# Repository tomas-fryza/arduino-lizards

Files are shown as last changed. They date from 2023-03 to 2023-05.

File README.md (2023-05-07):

# Measuring track for lizards

* [TODO](#TODO)
* [About](#About)
* [Usage](#Usage)
  * [PuTTY for Windows and Linux](#PuTTY-for-Windows-and-Linux)
  * [Terminal for Windows](#Terminal-for-Windows)
  * [Termite for Windows](#Termite-for-Windows)
* [Programming Arduino using PlatformIO](#Programming-Arduino-using-PlatformIO)
* [References](#References)

## TODO

* [x] Instructions for use & program
* [x] Logging data to a file
* [x] Selecting a suitable Monitor program (PuTTY, Terminal, Terminte, PlatformIO, ...)
* [x] Strengthen the mechanics
* [x] Add "start box"
* [x] Add (semi)waterproof paint
* [x] Cover electronics, 3D printing
* [x] Q: Consumption? A: approx. 350 milliamps
* [x] Q: IR wavelength A: 940 nm
* [ ] Q: Do I need to install USB driver? A: ??

## About

The measuring path contains 11 optical wounds, i.e. pairs of 940 nm infrared diodes and phototransistors. The first gate is the starting gate, the others are spaced 10 centimeters apart. The length of the track is thus 1 meter. Combine temperature and humidity sensor is used as well.

The ATmega328P microcontroller on the Arduino Nano board provides data acquisition from optical gates, time, temperature and humidity measurement, and data sending. The measuring track is powered via a mini USB connector, and at the same time, all data about the measurement progress is sent to the computer/laptop via this USB. Values are separated by semicolumn ";" symbol and can be subsequently processed, for example, in Excel.

## Usage

Once the microcontroller is programmed, on the PC/laptop just run one of the programs that can communicate with the serial port, such as PuTTY, Terminal, Termite, or other.

Perform the following steps to measure the speed of lizards:

1. Connect your computer/laptop to the Arduino board using a USB cable.

2. Run PuTTY, Terminal, Termite, or other serial terminal.

3. Configure terminal to save measured data to log text file.

4. Press `S` on keyboard to start the measurement. Status LED on Arduino board is turn on.

5. Place the lizard in the starting position and let it run through the entire track.

6. The individual times are written to the serial terminal (and the log file) after all gates have been interrupted or after the maximum time has expired. This is set to 60 seconds and can be reprogrammed in the Arduino Nano.

7. Go back to point 4 and repeat.

### PuTTY for Windows and Linux

1. Download, install, and run PuTTY open-source application for [Windows](https://putty.org/) or [Linux](https://www.tecmint.com/install-putty-on-linux/).

2. Set the following parameters:

   a. Category: Session Logging: **Printable output**

   b. Select Log file name, such as: `C:\Documents\your-user-name\putty_&Y&M&D-&T.log`

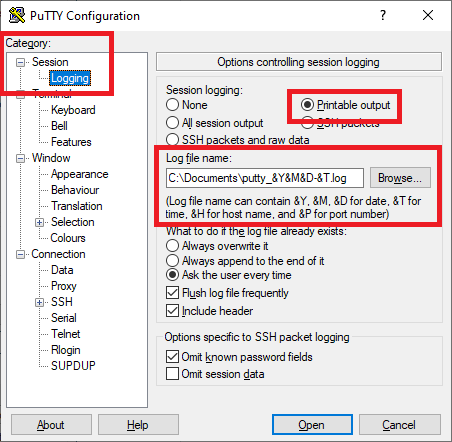
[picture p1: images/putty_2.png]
putty2
      

   c. Change Category to **Session** and select Connection type: **Serial**

   d. Serial line: put your com port, such as **COM5** (Windows) or `/dev/ttyUSB0` (Linux)

      > **Help:** To get the port name, run the Device Manager on Windows or type `dmesg` command to Terminal in Linux.

   e. Speed: **9600**

   f. Name Save Sessions: **LIZARDS** and click on **Save** button

   g. Anytime in the future, there is no need to configure PuTTY again, just double click on saved default settings **LIZARDS** to open the connection.

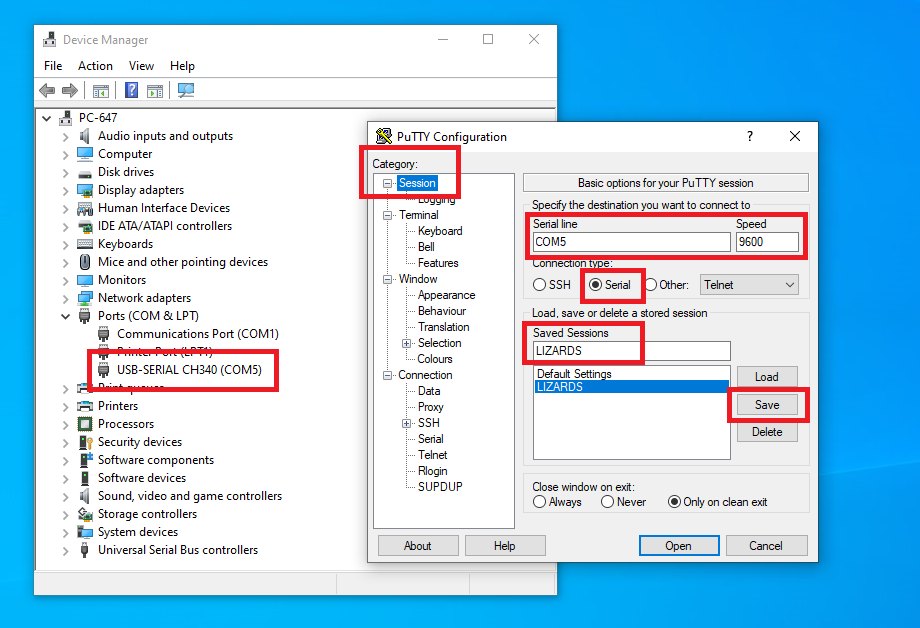
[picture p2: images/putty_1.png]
putty1
      

   h. Press `S` on keyboard to start each measurement.

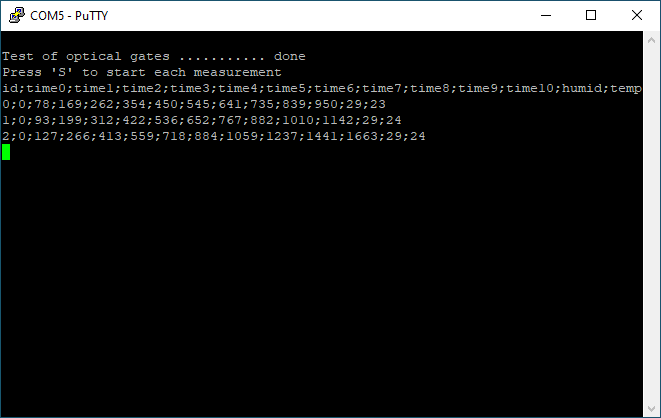
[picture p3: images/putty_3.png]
putty3
      

   i. Values are saved to your log file.

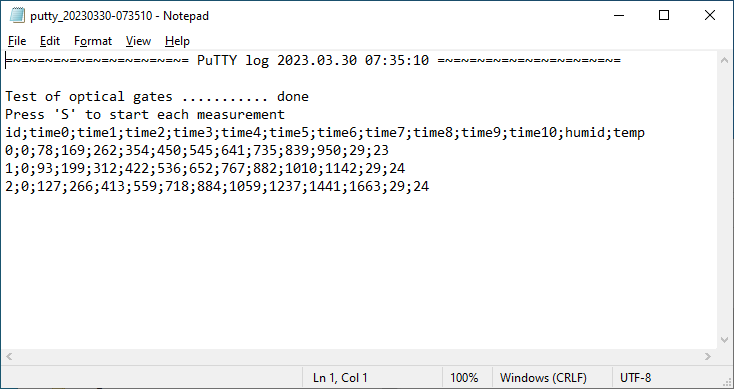
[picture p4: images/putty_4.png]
putty4
      

### Terminal for Windows

1. Download, unzip, and run the [Terminal](https://sites.google.com/site/terminalbpp/) application.

2. TBD

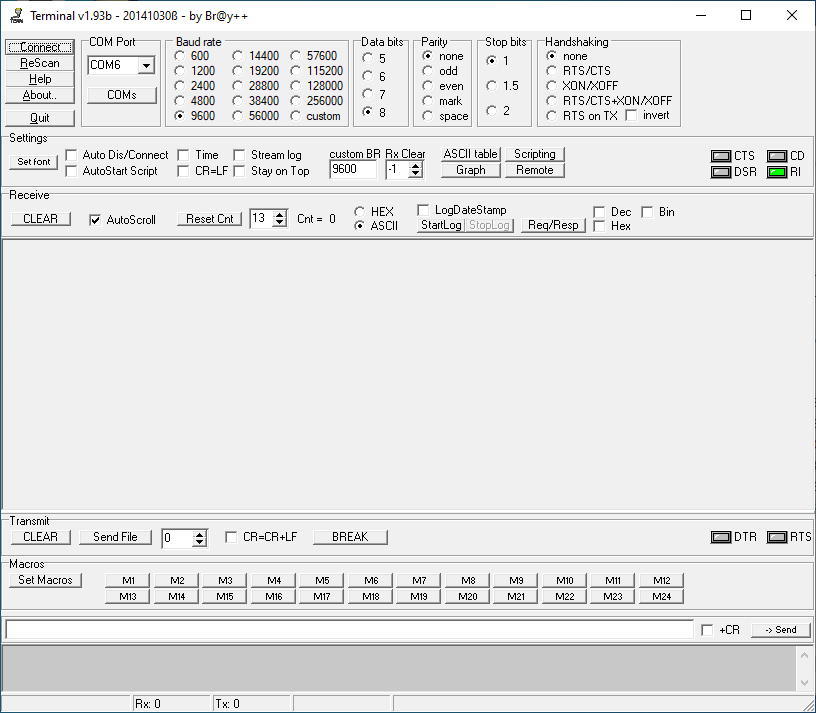
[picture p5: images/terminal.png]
terminal
   

### Termite for Windows

1. Download, install, and run [Termite](https://www.compuphase.com/software_termite.htm#EDITHISTORY) application.

2. TBD

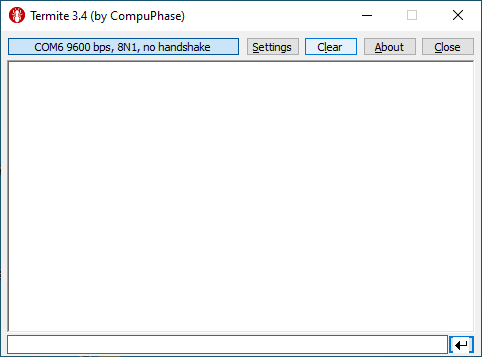
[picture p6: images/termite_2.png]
termite_2
   
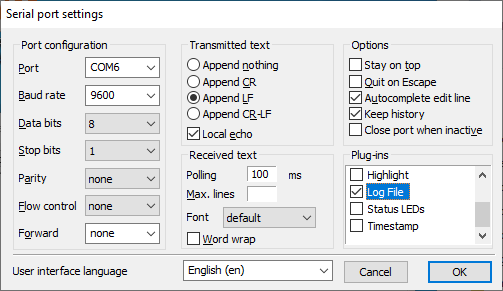
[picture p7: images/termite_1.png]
termite_1
   

## Programming Arduino using PlatformIO

1. Follow [Installation](https://github.com/tomas-fryza/digital-electronics-2/wiki/How-to-use-AVR-template-with-PlatformIO) instruction and download & install Visual Studio Code and PlatformIO plugin.

2. Download this repository, ie. in [browser](https://github.com/tomas-fryza/arduino-lizards), click on green `<> Code` button and select `Download ZIP`. Extract zip file to your local computer.

3. In Visual Studio Code, select **File > Open Folder...** and browse to `arduino-lizards/software/lizards` extracted folder.

4. In `platformio.ini` configuration file change your port name, such as COM5 for Windows:

   ```asm
   ; Custom monitor port
   ; Windows:
   monitor_port = COM[5]
   ; Linux:
   ; monitor_port = /dev/ttyUSB0
   ```

5. The application is programmed in C++ and is located in the file `src > main.cpp`

6. Compile the code, run the application, and open Serial Monitor to control it.

   Control icons

## References

1. Michaela Ryšavá. [Vývoj systému pro měření pohybových schopností malých živočichů](https://www.vut.cz/studenti/zav-prace/detail/141521)

2. Les Pounder. [How To Detect the COM Port for Any Serial Device in Windows](https://www.tomshardware.com/how-to/detect-com-port-windows-serial-port-notifier)

3. Martins D. Okoi. [How to Install PuTTY on Linux](https://www.tecmint.com/install-putty-on-linux/)

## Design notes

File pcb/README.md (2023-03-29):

# List of components

Symbol | Value | Package | Description
 :--   | :--   | :--     | :--
R1 | 10k | SMD 0805 | Resistor
R2 | 50 | SMD 0805 | Resistor
C | 100n | SMD 0603 | Capacitor
LM393D | | S08 | Dual differential comparator
L-53F3BT | | THT | LED IR, 940nm, 5mm
503PTC2E | | THT | Phototransistor, IR Detector 940nm
DG350-3.50-05P-14-02A | | | Screw terminal
BL 1 34 G | | | Female headers

## Possible future revisions

* switching transistors for IR leds
* smd packages for both IR leds and phototransistors
* more accurate temperature measurement
* lower consumption, battery powered
* ESP32, wi-fi/bluetooth comm?
* onboard logging: eeprom, sd card, ...
* display, button
* multiple IR LEDs on top of each other; the possibility of setting the necessary height of the optical gate

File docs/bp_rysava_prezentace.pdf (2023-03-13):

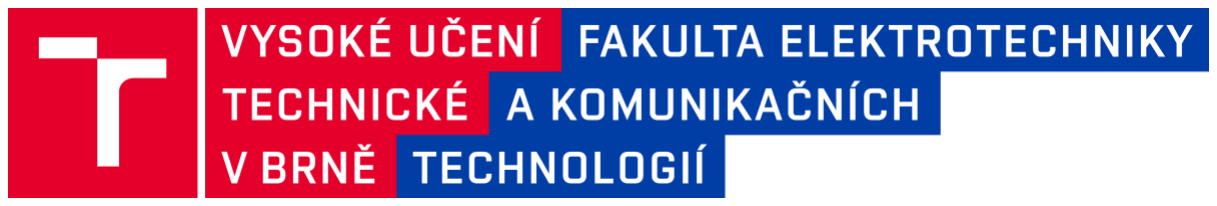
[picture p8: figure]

## Vývoj systému pro měření pohybových schopností malých živočichů

Bakalářská práce

Autor práce: MICHAELA RYŠAVÁ
Vedoucí práce: doc. Ing. TOMÁŠ FRÝZA, Ph.D.
Oponent: | doc. Mgr. KŘESTNÍ PŘÍJMENÍ, Ph.D.
| Brno, 14. 6. 2022

## Cíle práce

Téma
sestavit zařízení pro měření pohybu ještěrek na testovacích drahách Cíle semestrální práce
prozkoumat komerčně dostupné systémy
navrhnout vhodné metody měření a vyhodnocování dat
provést testování spolehlivosti navržených metod
Michaela Ryšavá | Vývoj systému pro měření pohybových schopností malých živočichů | 1 / 12

## Specifikace projektu

Cílem je změřit čas a rychlost na dráze s následujícími parametry:

rozměry:
šířka: 8 cm
délka: 1 m
varianty dráhy:
rovná dráha
zvlněná dráha
dráha ve tvaru U
další parametry:
povrch dráhy: smirkový
papír hrubosti 2000
materiál: plexisklo, dřevo požadavek na
odstranitelný horní kryt

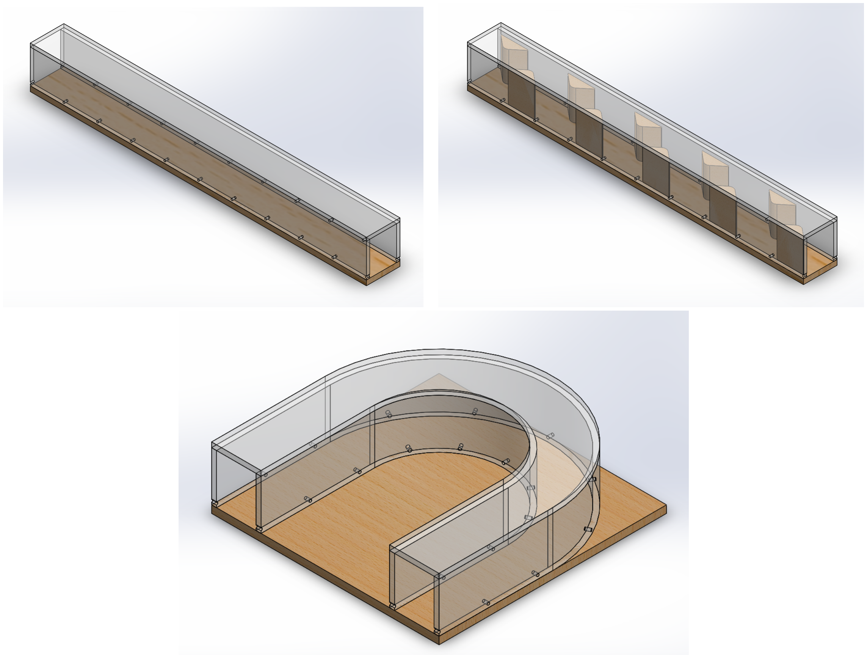
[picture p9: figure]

Michaela Ryšavá | Vývoj systému pro měření pohybových schopností malých živočichů | 2 / 12

## Metody měření

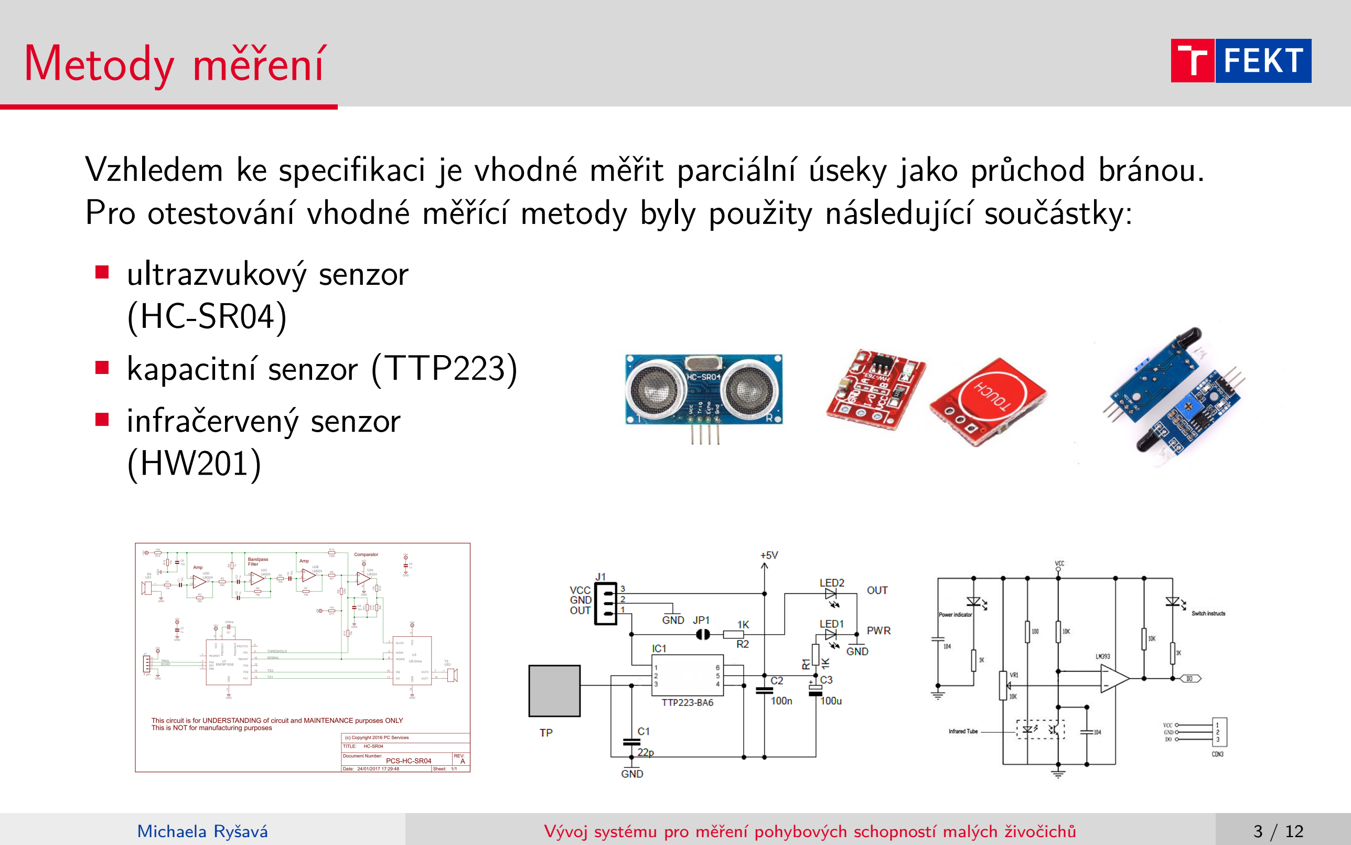
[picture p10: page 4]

Vzhledem ke specifikaci je vhodné měřit parciální úseky jako průchod bránou. Pro otestování vhodné měřící metody byly použity následující součástky:

ultrazvukový senzor
(HC-SR04)
kapacitní senzor (TTP223)
infračervený senzor
(HW201)
Michaela Ryšavá | Vývoj systému pro měření pohybových schopností malých živočichů | 3 / 12

## Výsledky testování metod měření

| Ultrazvukový senzor | Kapacitní senzor | Infračervený senzor | Optická brána
Schopnost detekce ještěrky | Ano | Není možné určit | Ano, na malé vzdálenosti | Ano
Spolehlivost detekce v prostoru 8cm | Ano | Ano | Ne | Ano
Diskrétnost řešení v rámci dráhy | Ano | Ano | Ne | Ano
Snadnost implementace na dráhu | Obtížné z hlediska výroby dráhy | Obtížné z hlediska těsnění | Snadné | Snadné
Nutnost přesné kalibrace | Není potřeba | Je potřeba | Je potřeba | Není potřeba
Citlivost na změny okolí | Zanedbatelné | Vlhkost | Světlo | Světlo
Michaela Ryšavá | Vývoj systému pro měření pohybových schopností malých živočichů | 4 / 12

## Návrh optické brány

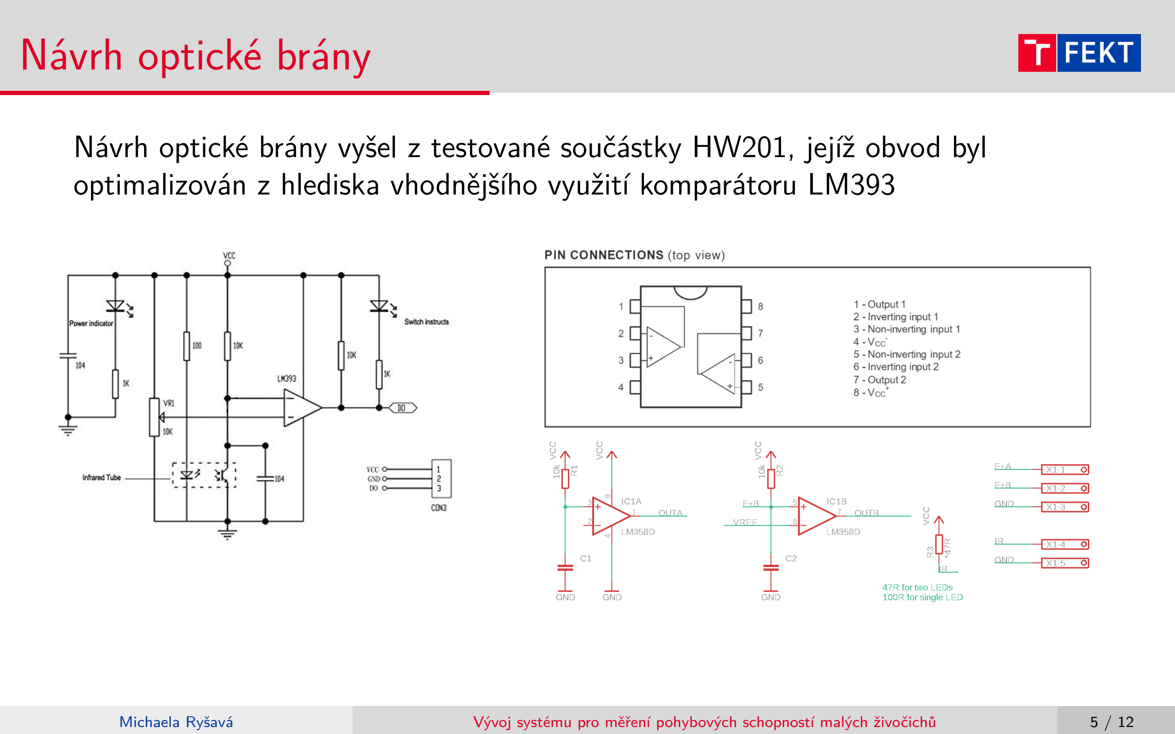
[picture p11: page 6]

Návrh optické brány vyšel z testované součástky HW201, jejíž obvod byl optimalizován z hlediska vhodnějšího využití komparátoru LM393

Michaela Ryšavá | Vývoj systému pro měření pohybových schopností malých živočichů | 5 / 12

## Deska plošných spojů

Rozvržení elektroniky bylo vzhledem k praktickým problémům při konstrukci dráhy soustředěno na jednu desku a podél samotné brány vedou pouze vodiče s optickými prvky.
Použité součástky:
rezistor 10 k, SMD 0805
rezistor 50, SMD 0805
kondenzátor 100 n, SMD 0603 komparátor LM393D, S08
infračervená LED, 5 mm, THT fototranzistor, 5 mm, THT
svorkovnice 5 pól, rozteč 3,5 mm dutinková lišta

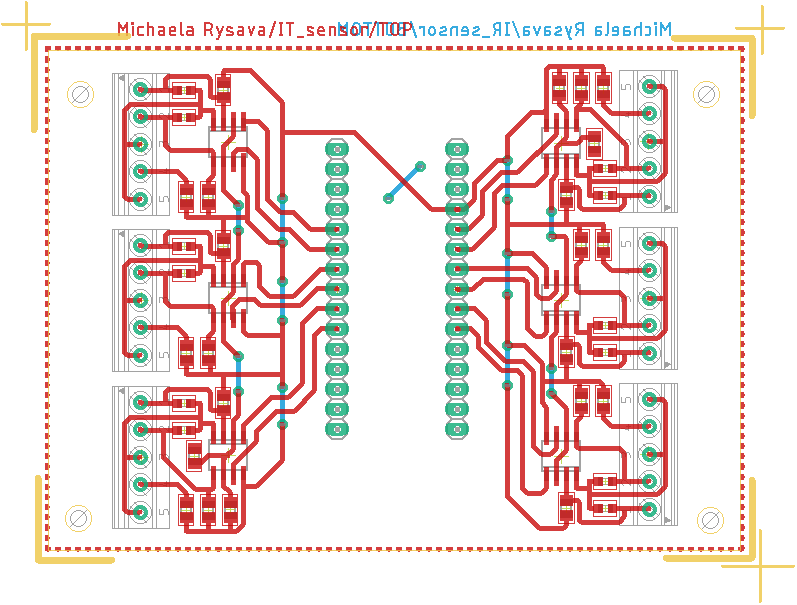
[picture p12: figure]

Michaela Ryšavá | Vývoj systému pro měření pohybových schopností malých živočichů | 6 / 12

## Celkové zapojení

Měřící systém je sestaven z částí:
optické prvky podél dráhy
deska plošných spojů s komparátory řídící jednotka Arduino Nano s firmwarem PC se softwarem

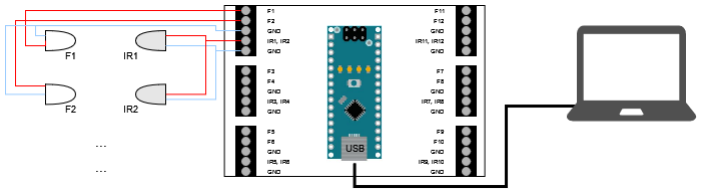
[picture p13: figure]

Michaela Ryšavá | Vývoj systému pro měření pohybových schopností malých živočichů | 7 / 12

## Programová část

Měření je ovládáno ze softwaru na počítači.

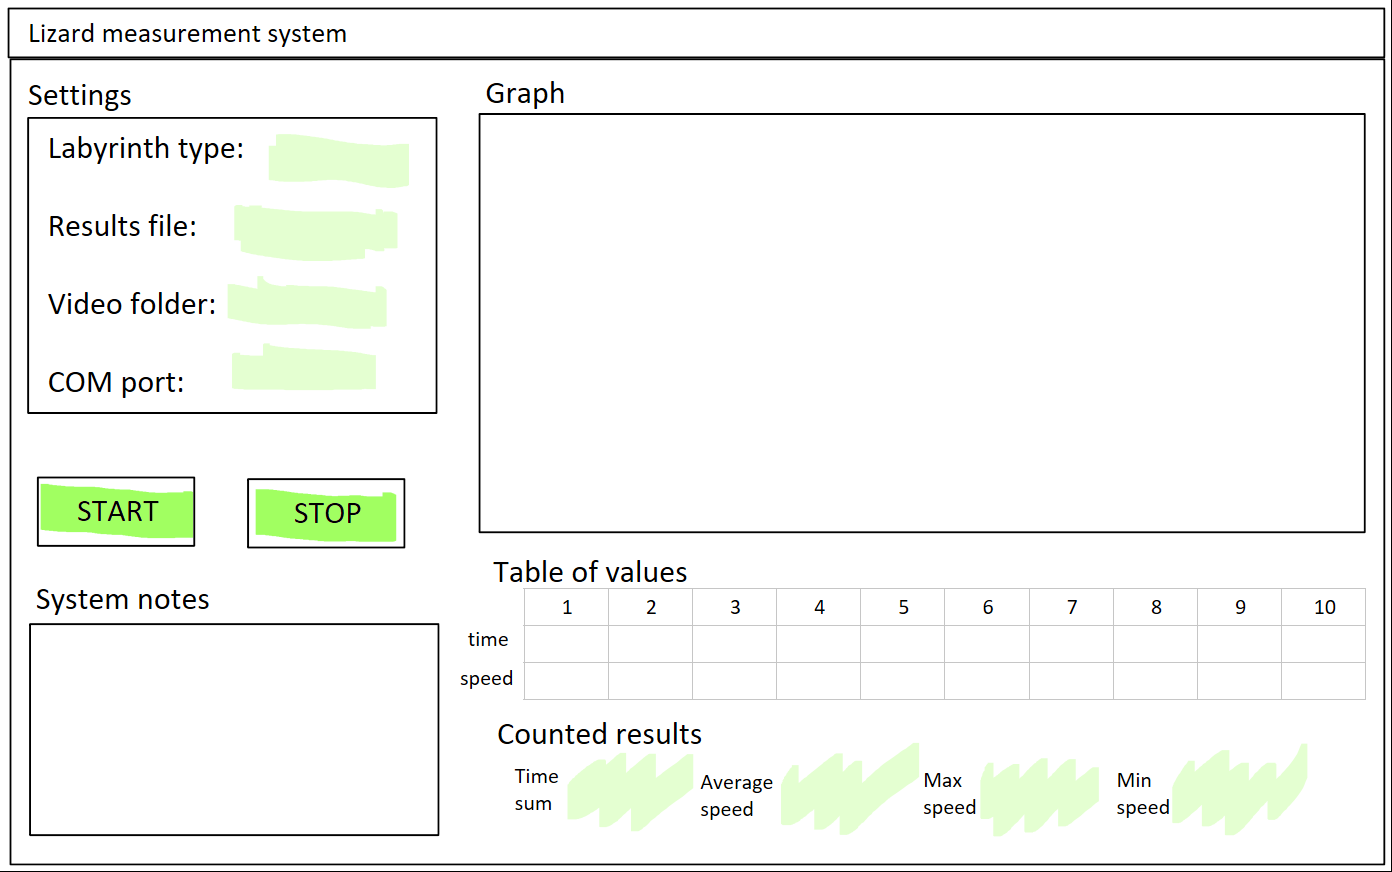
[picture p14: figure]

Uživatel má možnost:
nastavit základní parametry
měření
spustit a zastavit měření
příslušnými tlačítky
sledovat změřená data v
číselné i grafické podobě
kontrolovat správný průběh měření pomocí
systémových zpráv
Michaela Ryšavá | Vývoj systému pro měření pohybových schopností malých živočichů | 8 / 12

## Výsledky realizace systému

Konstrukce rovné dráhy
materiál: dřevotříska
váha: 3 kg
odolnost při manipulaci:
dostatečná
Elektronika
možnost zapojit až 12
optických bran
pinout pro zasazení
Arduino Nano
dlouhodobý provoz:
otestovány 4 hodiny

Programová část
Firmware
aktivní běh pouze při samotném měření automatická kontrola nefunkčních optických bran
možnost začít měření z libovolného místa dráhy
Software
implementování GUI
průběžné zobrazování naměřených hodnot vykreslení orientačního grafu rychlosti automatický export do souboru (třízení dat podle data a času měření)
Michaela Ryšavá | Vývoj systému pro měření pohybových schopností malých živočichů | 9 / 12

# Děkuji za pozornost!

Michaela Ryšavá | Vývoj systému pro měření pohybových schopností malých živočichů | 10 / 12

## Otázky

Jaké další vhodné koncepce by se daly použít z pohledu systémové architektury? Tedy místo PC->USB->ARDUINO

Lze například zcela vynechat PC a data ukládat přímo na USB flash disk koncepce Mikrokontroler->USB
koncpce Mikrokontroler->Raspberry Pi->USB
Nebo místo počítače využít chytrý telefon či tablet a spojení provést beztrátově koncepce Mikrokontroler->Wifi->Android
Michaela Ryšavá | Vývoj systému pro měření pohybových schopností malých živočichů | 11 / 12

## Otázky

Je možné realizovat komunikaci mezi PC a Arduinem jiným způsobem než přes USB? Jaké existují moduly případně moduly?

Komunikaci lze realizovat také bezdrátově
wifi
bluetooth

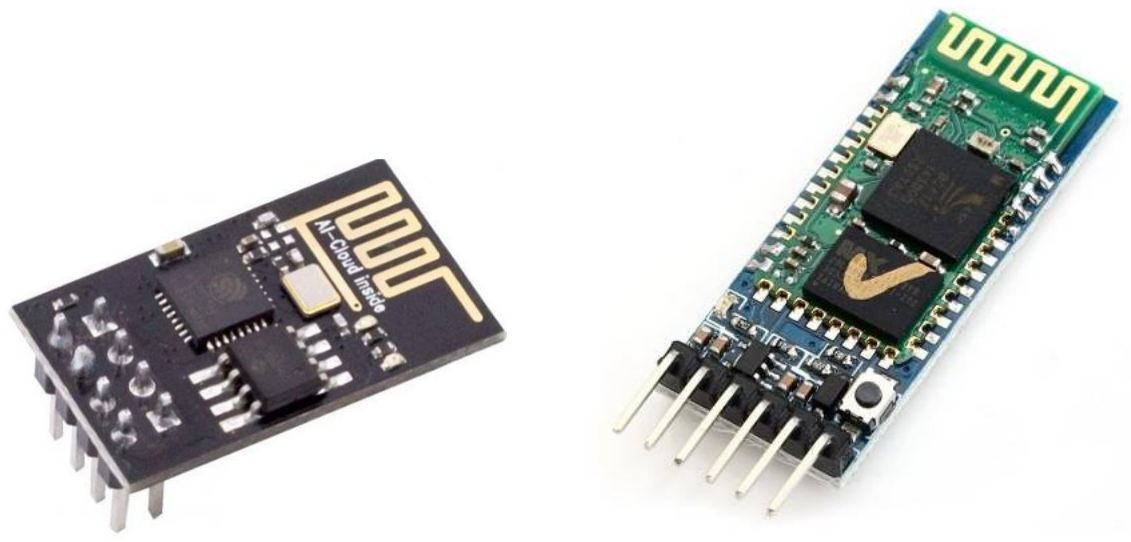
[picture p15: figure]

Michaela Ryšavá | Vývoj systému pro měření pohybových schopností malých živočichů | 12 / 12

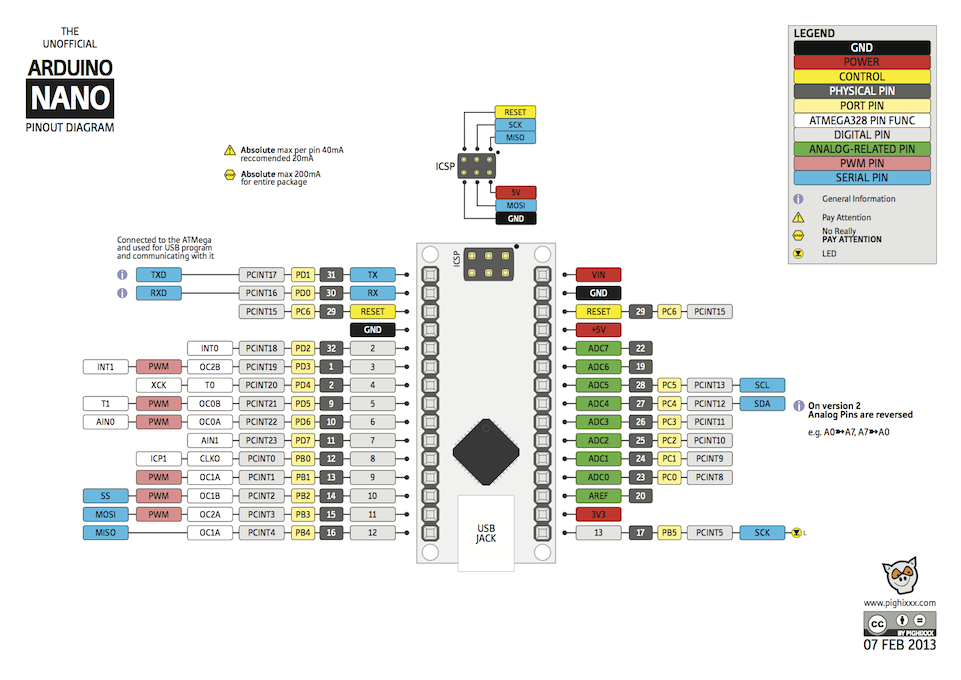
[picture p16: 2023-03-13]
docs/arduino_nano_pinout.png

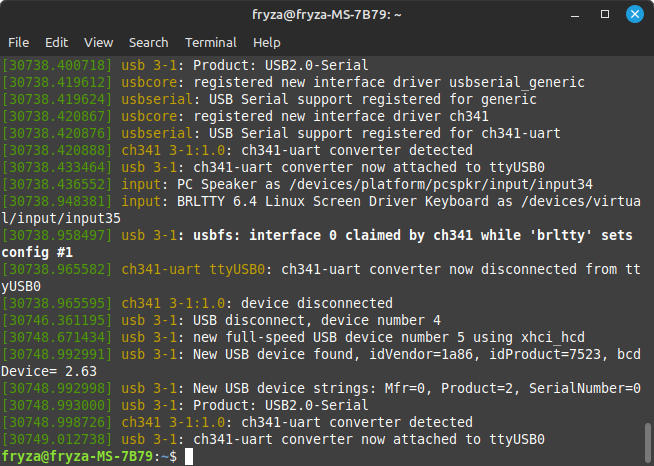
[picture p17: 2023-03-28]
images/linux_port.png

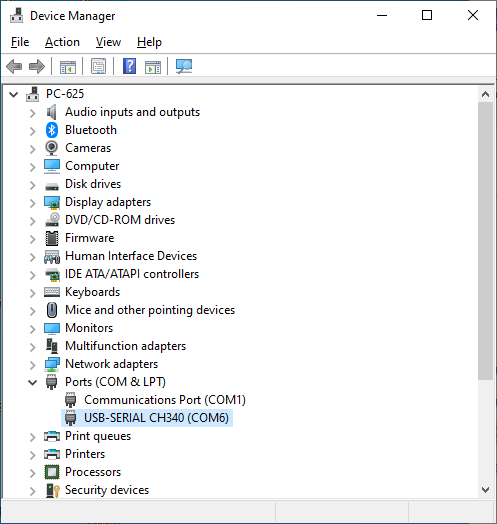
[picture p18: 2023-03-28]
images/windows_device-manager.png

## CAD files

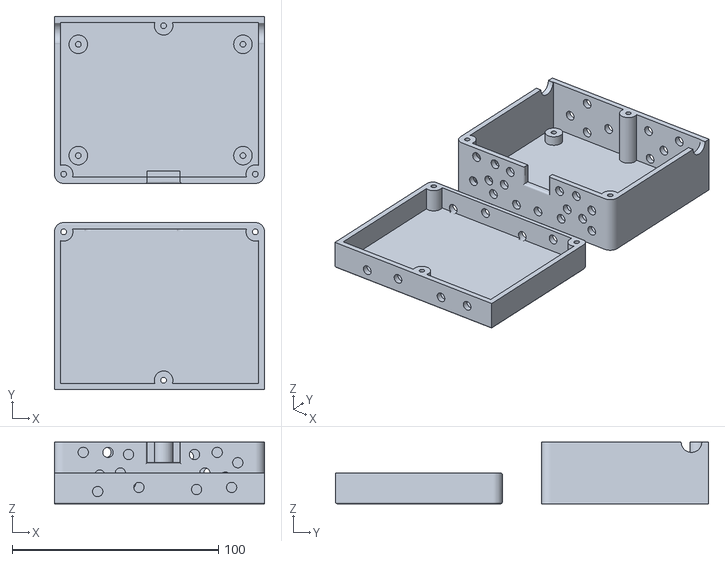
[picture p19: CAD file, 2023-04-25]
3d/lizard_v1.1.stl
102.0 x 181.0 x 30.0

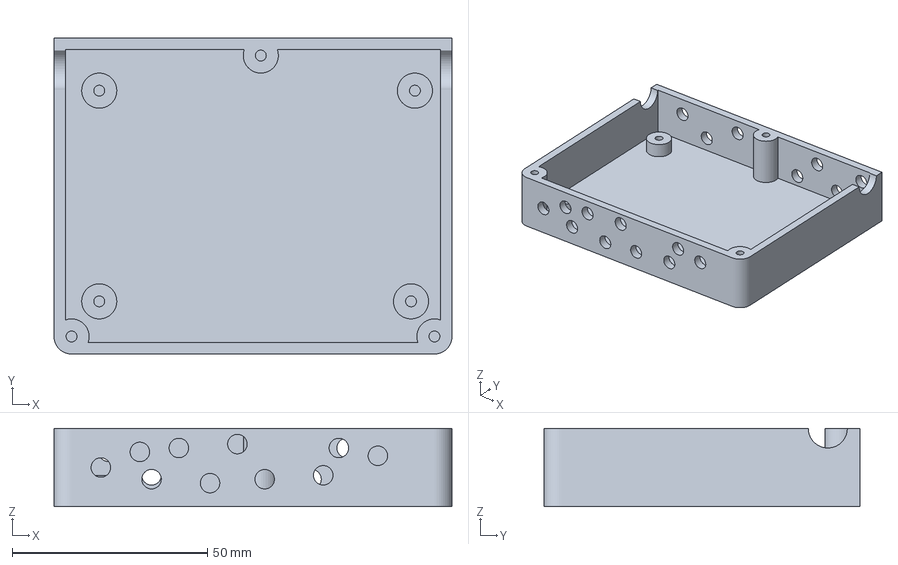
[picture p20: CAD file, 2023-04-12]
3d/lizard_v1.3mf
102.0 x 81.0 x 20.0 mm

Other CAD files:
3d/lizard_v1.stl

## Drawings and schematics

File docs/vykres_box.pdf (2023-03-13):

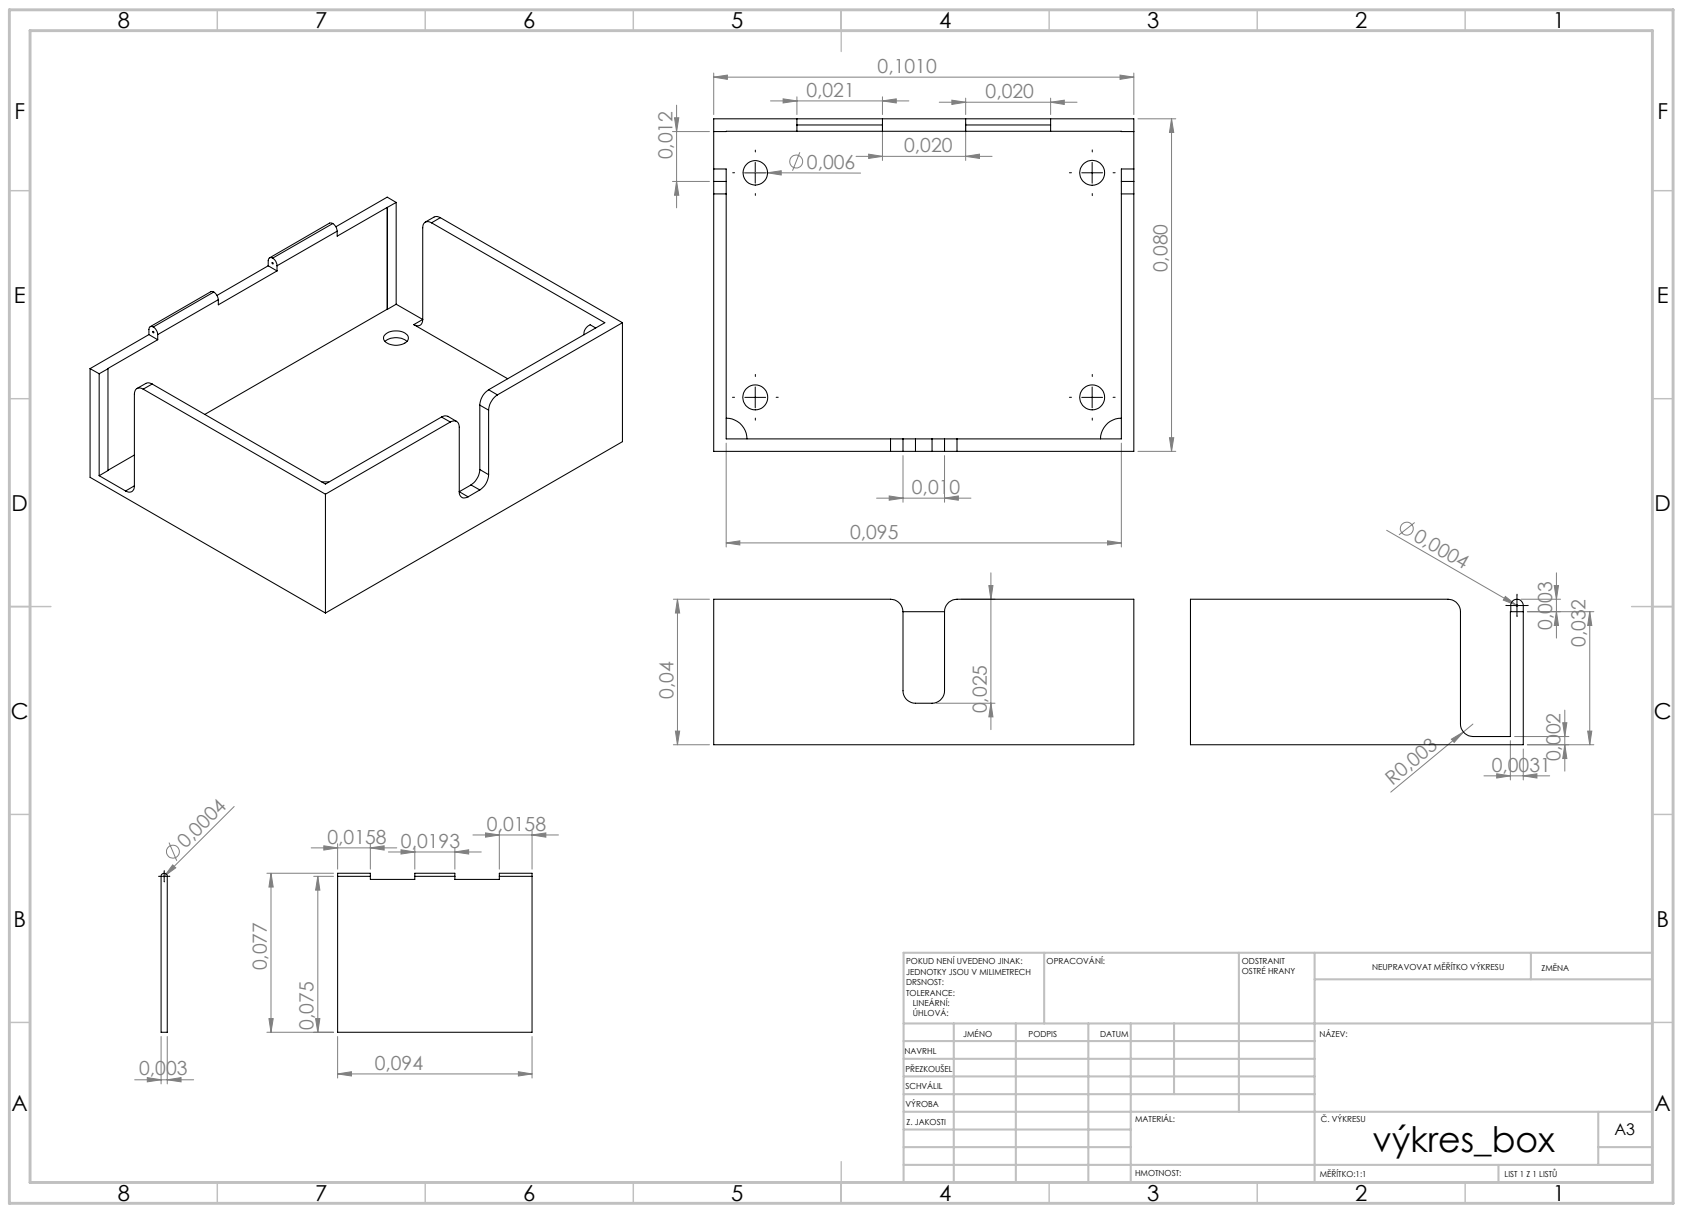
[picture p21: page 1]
MĚŘÍTKO:1:1; LIST 1 Z 1 LISTŮ; NEUPRAVOVAT MĚŘÍTKO VÝKRESU; ZMĚNA; OSTRÉ HRANY; POKUD NENÍ UVEDENO JINAK:; OPRACOVÁNÍ:; JEDNOTKY JSOU V MILIMETRECH

JMÉNO | PODPIS | DATUM | | | | NÁZEV:
Z. JAKOSTI | | | | MATERIÁL: | Č. VÝKRESU výkres_box HMOTNOST: | A3

NAVRHL
PŘEZKOUŠEL
SCHVÁLIL
VÝROBA

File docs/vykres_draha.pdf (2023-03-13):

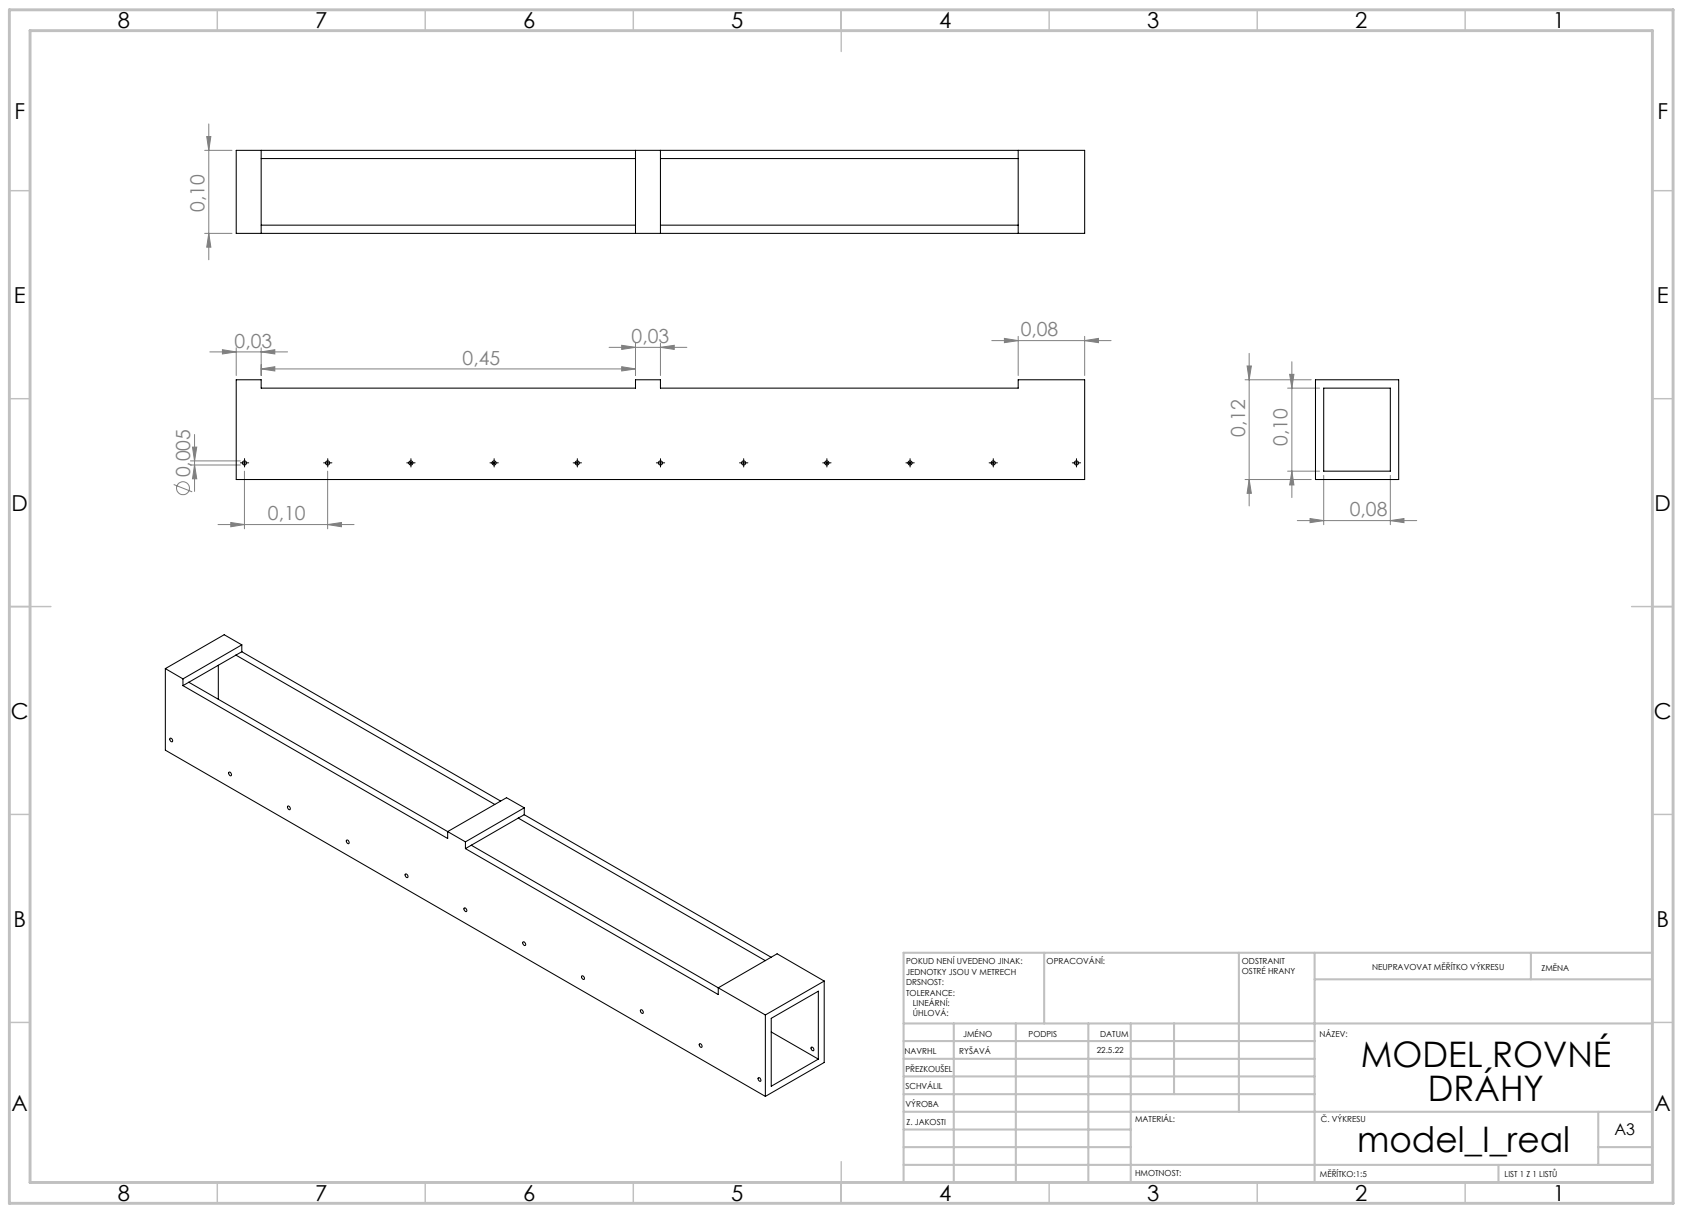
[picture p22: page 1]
MĚŘÍTKO:1:5; LIST 1 Z 1 LISTŮ; NEUPRAVOVAT MĚŘÍTKO VÝKRESU; ZMĚNA; OSTRÉ HRANY; POKUD NENÍ UVEDENO JINAK:; OPRACOVÁNÍ:; JEDNOTKY JSOU V METRECH

JMÉNO | PODPIS | DATUM | | | | NÁZEV: MODEL ROVNÉ DRÁHY
Z. JAKOSTI | | | | MATERIÁL: | Č. VÝKRESU model_I_real | A3

NAVRHL | RYŠAVÁ | | 22.5.22
PŘEZKOUŠEL
SCHVÁLIL
VÝROBA

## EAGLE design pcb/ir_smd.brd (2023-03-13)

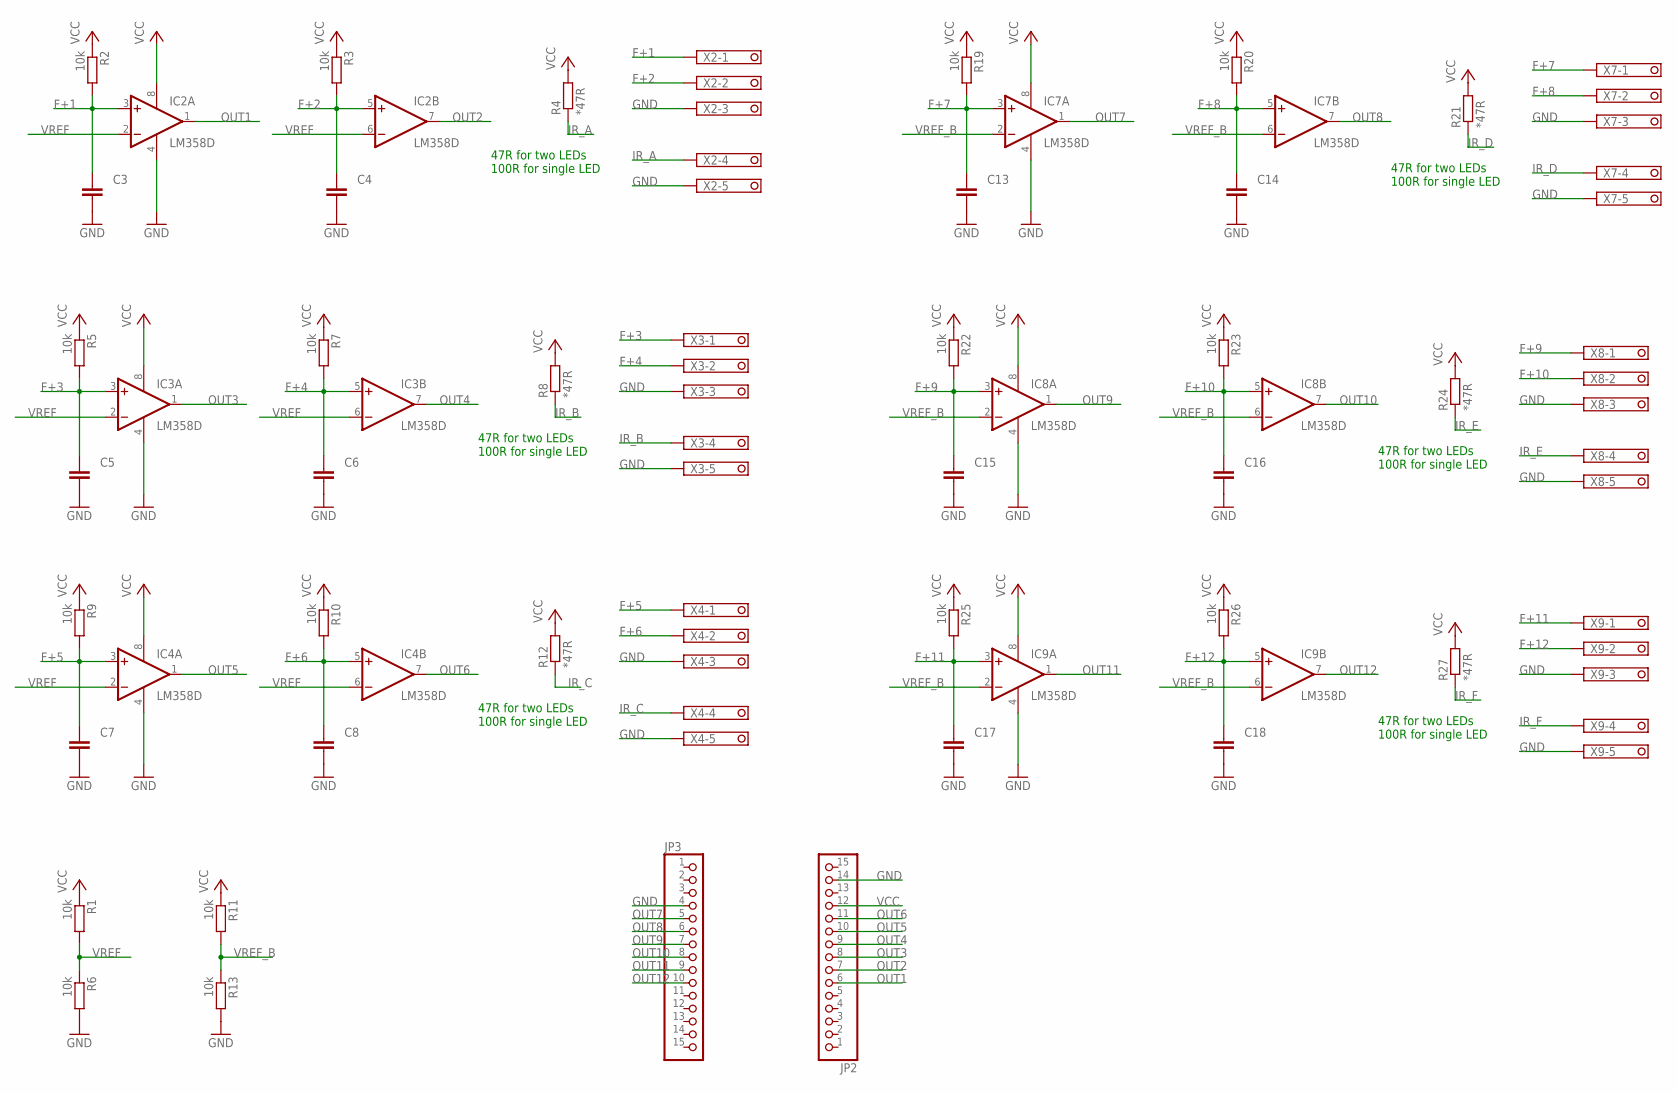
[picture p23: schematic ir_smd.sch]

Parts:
C3, C4, C5, C6, C7, C8, C13, C14, C15, C16, C17, C18: C-EUC0603; C0603
IC2, IC3, IC4, IC7, IC8, IC9: LM358D; SO08
JP2, JP3: PINHD-1X15; 1X15
R1, R2, R3, R5, R6, R7, R9, R10, R11, R13, R19, R20, R22, R23, R25, R26: 10k; R0805
R4, R8, R12, R21, R24, R27: *47R; R0805
X2, X3, X4, X7, X8, X9: 1751277

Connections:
F+1: C3.1, IC2.3 (+IN), R2.2, X2.1
F+2: C4.1, IC2.5 (+IN), R3.2, X2.2
F+3: C5.1, IC3.3 (+IN), R5.2, X3.1
F+4: C6.1, IC3.5 (+IN), R7.2, X3.2
F+5: C7.1, IC4.3 (+IN), R9.2, X4.1
F+6: C8.1, IC4.5 (+IN), R10.2, X4.2
F+7: C13.1, IC7.3 (+IN), R19.2, X7.1
F+8: C14.1, IC7.5 (+IN), R20.2, X7.2
F+9: C15.1, IC8.3 (+IN), R22.2, X8.1
F+10: C16.1, IC8.5 (+IN), R23.2, X8.2
F+11: C17.1, IC9.3 (+IN), R25.2, X9.1
F+12: C18.1, IC9.5 (+IN), R26.2, X9.2
GND: C3.2, C4.2, C5.2, C6.2, C7.2, C8.2, C13.2, C14.2, C15.2, C16.2, C17.2, C18.2, IC2.4 (V-), IC3.4 (V-), IC4.4 (V-), IC7.4 (V-), IC8.4 (V-), IC9.4 (V-), JP2.14, JP3.4, R6.2, R13.2, X2.3, X2.5, X3.3, X3.5, X4.3, X4.5, X7.3, X7.5, X8.3, X8.5, X9.3, X9.5
IR_A: R4.1, X2.4
IR_B: R8.1, X3.4
IR_C: R12.1, X4.4
IR_D: R21.1, X7.4
IR_E: R24.1, X8.4
IR_F: R27.1, X9.4
OUT1: IC2.1 (OUT), JP2.6
OUT2: IC2.7 (OUT), JP2.7
OUT3: IC3.1 (OUT), JP2.8
OUT4: IC3.7 (OUT), JP2.9
OUT5: IC4.1 (OUT), JP2.10
OUT6: IC4.7 (OUT), JP2.11
OUT7: IC7.1 (OUT), JP3.5
OUT8: IC7.7 (OUT), JP3.6
OUT9: IC8.1 (OUT), JP3.7
OUT10: IC8.7 (OUT), JP3.8
OUT11: IC9.1 (OUT), JP3.9
OUT12: IC9.7 (OUT), JP3.10
VCC: IC2.8 (V+), IC3.8 (V+), IC4.8 (V+), IC7.8 (V+), IC8.8 (V+), IC9.8 (V+), JP2.12, R1.1, R2.1, R3.1, R4.2, R5.1, R7.1, R8.2, R9.1, R10.1, R11.1, R12.2, R19.1, R20.1, R21.2, R22.1, R23.1, R24.2, R25.1, R26.1, R27.2
VREF: IC2.2 (-IN), IC2.6 (-IN), IC3.2 (-IN), IC3.6 (-IN), IC4.2 (-IN), IC4.6 (-IN), R1.2, R6.1
VREF_B: IC7.2 (-IN), IC7.6 (-IN), IC8.2 (-IN), IC8.6 (-IN), IC9.2 (-IN), IC9.6 (-IN), R11.2, R13.1

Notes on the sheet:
47R for two LEDs 100R for single LED

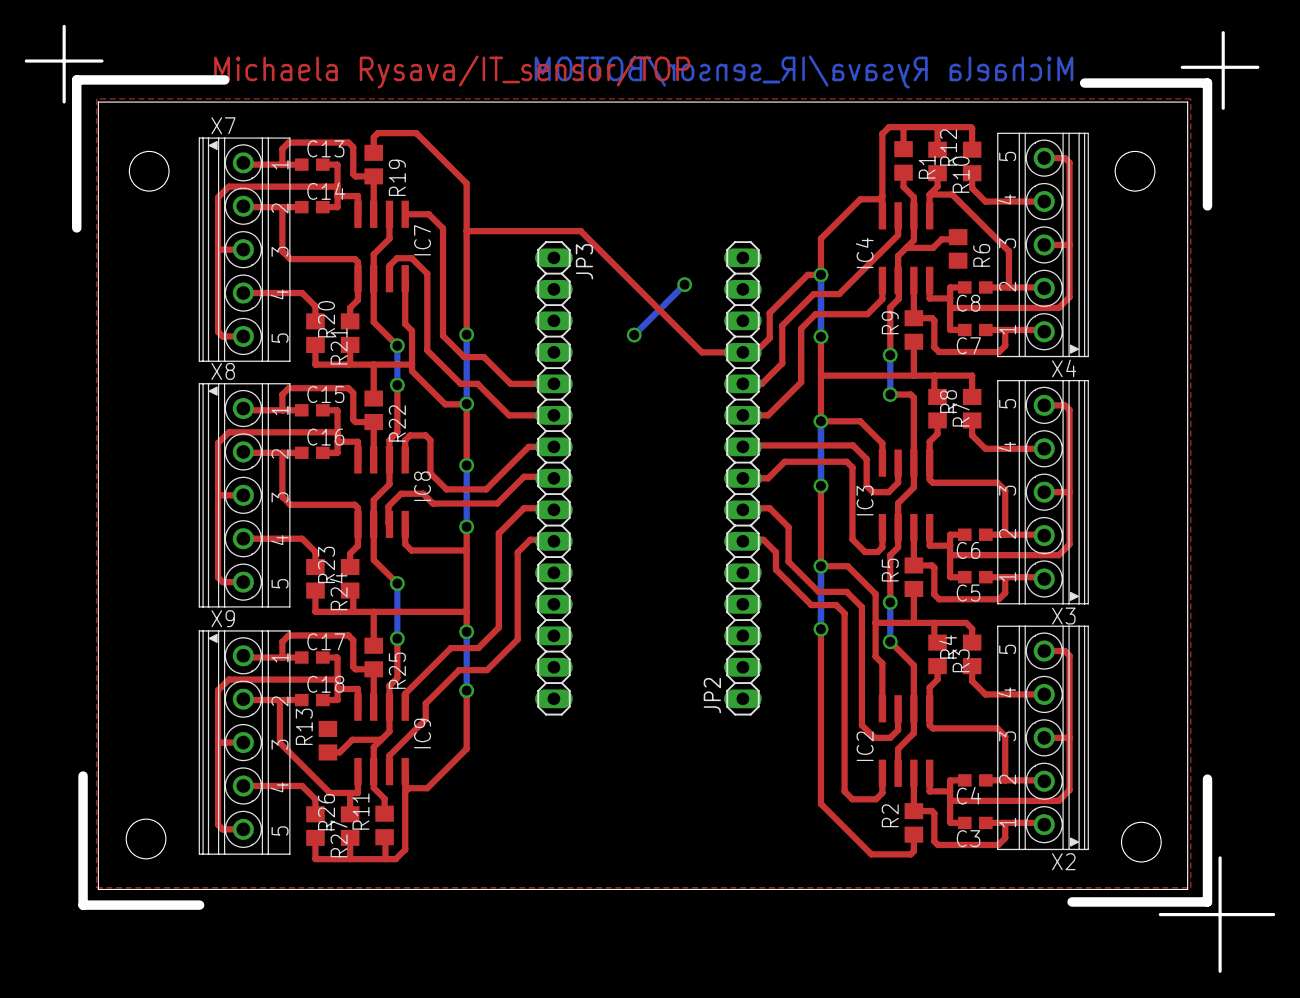
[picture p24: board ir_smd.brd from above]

Board: 2 copper layers, 87.8 x 63.5 mm, 48 parts (0 on the bottom side), 34 nets.

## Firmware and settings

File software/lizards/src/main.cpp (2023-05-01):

/**********************************************************************
 * 
 * Measuring the speed of lizards using optical gates.
 * ATmega328P (Arduino Nano), 16 MHz, PlatformIO
 *
 * Copyright (c) 2023 Tomas Fryza
 * Dept. of Radio Electronics, Brno University of Technology, Czechia
 * This work is licensed under the terms of the MIT license.
 *
 **********************************************************************/


/* Defines -----------------------------------------------------------*/
#define TIMEOUT_MILLIS 60000  // 60 seconds

#define NGATES 11     // Number of optical gates
#define PIN_LED 13    // SCK
#define PIN_DHT11 11  // MOSI

/* Includes ----------------------------------------------------------*/
#include "Arduino.h"
#include <dht.h>


/* Global variables --------------------------------------------------*/
// Pin ID for optical gates
uint8_t gates[NGATES] = {
        7, 6, 5, 4, 3, 2, 16, 17, 18, 19, 15
    };

// Temperature and humidity sensor DHT11
dht DHT;

uint8_t measure_en = 0;    // Enable measurement
uint8_t measure_id = 0;    // Measurement ID
uint8_t measured_num = 0;  // Total number of measured gates


/**********************************************************************
 * Function: setup()
 * Purpose:  Setup function where the program execution begins. Init 
 *           serial communications, GPIO pins, and perform functionality
 *           tests of optical gates.
 * Returns:  none
 **********************************************************************/
void setup()
{
    // Setup UART communication with Serial monitor
    Serial.begin(9600);

    // Setup input pins for optical gates
    for (uint8_t i = 0; i < NGATES; i++) {
        pinMode(gates[i], INPUT_PULLUP);
    }

    // Setup output pin for status LED
    pinMode(PIN_LED, OUTPUT);

    // Setup input pin for DHT11 sensor
    pinMode(PIN_DHT11, INPUT_PULLUP);

    // Test received signals from all gates
    Serial.print("\r\nTest of optical gates ");
    for (uint8_t i = 0; i < NGATES; i++) {
        uint8_t state = digitalRead(gates[i]);
        if (state == 0) {  // Signal OK
            Serial.print(".");
        }
        else {  // No received signal
            Serial.print("#");
            Serial.print(i, DEC);
            Serial.print(" Error ");
        }
        delay(100);
    }
    Serial.println(" done");

    Serial.println("Press 'S' to start each measurement");
    Serial.println("");
    Serial.println("id;time0;time1;time2;time3;time4;time5;time6;time7;time8;time9;time10;humid;temp;idAnimal;tempAnimal");
}


/**********************************************************************
 * Function: loop()
 * Purpose:  Infinite loop. This function is executed over and over 
 *           again. Check values from optical gates, measure the time
 *           and send it to the UART. Use Serial Monitor to view it.
 * Returns:  none
 **********************************************************************/
void loop()
{
    uint8_t incoming;

    uint8_t measured_status[NGATES] = {0};
    unsigned long measured_time[NGATES] = {0};
    unsigned long start_millis;
    unsigned long current_millis;

    // Wait for Start from UART: key "S"
    if (Serial.available() > 0) {
        incoming = Serial.read();
        if ((incoming == 'S') || (incoming == 's')) {
            measure_en = 1;
        }
    }

    // Start measurement
    if (measure_en == 1) {
        // Turn Status LED on
        digitalWrite(PIN_LED, 1);

        // Display measurement ID
        Serial.print(measure_id++);

        // Wait for the first optical gate
        uint8_t i = 0;
        uint8_t state;
        do {
            i++;
            if (i >= NGATES)
                i = 0;
            state = digitalRead(gates[i]);
        } while (state == 0);

        // Reference time of the first gate
        start_millis = millis();

        // Store measured values
        measured_status[i] = 1;
        measured_time[i] = 0;
        measured_num = 1;
        // Serial.println(i);

        // Read all other optical gates
        do {
            i++;
            if (i >= NGATES)
                i = 0;
            state = digitalRead(gates[i]);
            current_millis = millis();
            if (state == 1) {
                if (measured_status[i] == 0) {
                    measured_status[i] = 1;
                    measured_time[i] = current_millis - start_millis;
                    measured_num++;
                    // Serial.println(i);
                }
            }
        } while ((measured_num < NGATES) && (current_millis - start_millis <= TIMEOUT_MILLIS));

        // Display measured times
        for (uint8_t i = 0; i < (NGATES); i++) {
            Serial.print(";");
            if (measured_status[i] == 1)
                Serial.print(measured_time[i]);
            else
                Serial.print("-");
        }

        // Read and display DHT11 data
        DHT.read11(PIN_DHT11);
        Serial.print(";");
        Serial.print(DHT.humidity, 0);
        Serial.print(";");
        Serial.print(DHT.temperature, 0);

        // Add columns for animal ID and body temperature
        Serial.println(";NA;NA");

        // Clear measured values
        for (uint8_t i = 0; i < (NGATES); i++) {
            measured_status[i] = 0;
            measured_time[i] = 0;
        }

        // Turn Status LED off
        digitalWrite(PIN_LED, 0);

        // Measurement is over
        measure_en = 0;
    }
}

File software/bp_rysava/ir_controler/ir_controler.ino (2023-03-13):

  int pinOut [11] = {2, 3, 4, 5, 6, 7, 19, 18, 17, 16, 15}; //vzdy 5. pin od shora

  //int time_measured [11]; //matice pro vysledne casy
  int sensor = 0;
  bool run_direction = 0;
  bool experiment_run = 0;
  bool stav;
  bool eneable = 0;
  int input_string = 0;
  unsigned long time1 = 0;
  unsigned long time2 = 0;
  unsigned long measured_time = 0;
  int last = 10;
  int first = 0;
  int err_count = 0;
  int err_pin [3] = {-1, -1, -1};
  
void setup() {
  Serial.begin(9600);
  for (int i=0; i < last+1; i++){
    pinMode(pinOut[i], INPUT_PULLUP);
  }
  
  //pokud je brana difoltne prerusena, nahlasi se chyba a cislo brany
  for (int i=0; i < last+1; i++){
      stav = !(digitalRead(pinOut[i]));
      if (not stav) {
        Serial.print("ERR");
        Serial.print(" ");
        Serial.print(i);
        Serial.println();
        if (err_count<3){
          err_pin[err_count]=i;
          err_count++;
        }
        else{
          Serial.print("SER_ERR");  //pokud jsou preruseny vice nez 3 chyby, nahlasi se severe error
          Serial.print(" ");
          Serial.print(i);
          Serial.println();
        }
        //reseni nefunkcnich koncovych bran
        if (i == first){ 
          first = first+1;
        }
        else if (i==last){
          if (last-1 != err_pin[0] and last-1 != err_pin[1] and last-1 != err_pin[2]){
            last = last-1;
          }
          else if(last-2 != err_pin[0] and last-2 != err_pin[1] and last-2 != err_pin[2]){
            last = last-2;
          }
          else{
            last = last-3;
          }
        }
      }
  }
}


//hlavní program
void loop() {
//čtení eneable
  if (Serial.available() > 0){
    input_string = Serial.read();
    if (input_string == 48){
      eneable = 0;
    }
    else if (input_string == 49){
      eneable = 1;
    }
    //pokud je pokus zastaven externě, program vrátí poslední čas
    if (eneable == 0 & experiment_run == 1){
      time2 = millis();
      measured_time = time2-time1;
      time1 = time2;
      Serial.print("x");
      Serial.print(" ");
      Serial.print(measured_time);
      Serial.println();
      experiment_run = 0;
    }
  }  
  
  //povolení pokusu
  if (eneable){

    //pokus ještě nezačal, hlídá se první přerušení brány
    if (not experiment_run){
      for (int i=0; i < last+1; i++){
        stav = !(digitalRead(pinOut[i]));
        //pokud je přerušena první nebo poslední brána, určí se směr měření a zahájí se pokus
        if (not stav and i != err_pin[0] and i != err_pin[1] and i != err_pin[2]) {
          if (i==first){
            run_direction = 0;
          }else if (i==last){
            run_direction = 1;
          }else {
            //send warning
            Serial.print("WAR ");
            Serial.print(i);
            Serial.println();

            if (i>5){
              run_direction = 1;
            }else{
              run_direction = 0;
            }
          }
          experiment_run=1;
          sensor = i;
          //set timer
          time1 = millis(); 
          Serial.print(i);
          Serial.print(" 0");
          Serial.println();
        }
      }
      
    }else {
      for (int i=0; i < last+1; i++){
        stav = !(digitalRead(pinOut[i]));
         if (not stav and i != err_pin[0] and i != err_pin[1] and i != err_pin[2]){             //pokud byla prerusena nejaka brana
          if (not run_direction){   //pokud je smer 0-11
            if (sensor<i){          //pokud byla prerusena nektera dalsi brana v poradi
              //write time
              time2 = millis();
              measured_time = time2-time1;
              time1 = time2;
              Serial.print(i);
              Serial.print(" ");
              Serial.print(measured_time);
              Serial.println();
              sensor = i;
            }
            if (i==last){
              eneable=0;
              Serial.print("END");
              experiment_run = 0;
            }
          }else{                    //pokud je smer v opacnem poradi
            if (sensor>i){          //pokud byla prerusena nektera dalsi brana v poradi
              //write time
              time2 = millis();
              measured_time = time2-time1;
              time1 = time2;
              Serial.print(i);
              Serial.print(" ");
              Serial.print(measured_time);
              Serial.println();
              sensor = i;
            }
            if (i==first){
              eneable=0;
              Serial.print("END");
              experiment_run = 0;
            }
          }
        }
      }
    }
  }
}

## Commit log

2023-03-13 Initial commit - Rysava BP
    [ir_smd.brd, ir_smd.sch]
2023-03-13 Arduino Nano schamatic added
2023-03-14 Minor debug prints moved
2023-03-15 Optical gates pin ID corrected
    [main.cpp]
2023-03-18 Log2file filter added
2023-03-29 General info about device and usage created
2023-04-12 3D box created, ver1
    [lizard_v1.3mf, lizard_v1.stl]
2023-04-25 Box with cover created
    [lizard_v1.1.stl]
2023-04-30 Add columns to log file
    Prepares empty columns with standard column names for animal ID and body temperature
